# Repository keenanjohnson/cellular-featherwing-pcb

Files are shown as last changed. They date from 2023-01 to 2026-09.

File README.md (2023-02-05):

# cellular-featherwing-pcb
The PCB Design for a Cellular Adafruit Featherwing based on the Quectel BG96 LTE Cat M1 &amp; Cat NB1.

Based on the excellent [qTop Adafruit Feather design](https://www.iot-bots.com/collections/qtop-cellular/products/qtop-adafruit-feather-compatible-lte-cat-m1-nb-iot-gnss-shield) by [IOT-BOTS](https://www.iot-bots.com/)

# Current Status
This PCB is currently being produced by [JLPCB](https://jlcpcb.com/). The design has NOT been verified as functional yet until first production samples are tested.



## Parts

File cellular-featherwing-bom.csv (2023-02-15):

Comment | Designator | Footprint | JLCPCB Part #（optional）
22uF | C1,C2,C6,C7,C8 | 22 uF 0603 Capacitor | C59461
2.2uF | C3 | 2.2 uF 0402 Capacitor | C12530
0.1uF | C4,C11,C29,C34 | 0.1 uF 0402 Capacitor | C1525
33pF | C16,C17,C18,C22,C23 | 33 pF 0402 Capacitor | C1562
100nF | C20,C21 | 100 nF 0402 Capacitor | C1525
10pF | C24,C25 | 10 pF 0402 Capacitor | C32949
C_Polarized_US | C26,C28 | 330 碌F Molded Tantalum Capacitors 6 V 1411 (3528 Metric) 800mOhm | C347529
4.7uF | C30,C31,C33 | 4.7 碌F 卤20% 10V Ceramic Capacitor X5R 0402 (1005 Metric) | C23733
SMF05C | D1 | 12.5V Clamp 8A (8/20碌s) Ipp Tvs Diode Surface Mount SC-70-6 | C85191
0 Ohm Resistor | FB1,FB2,FB3,FB4 | 0805 (2012 Metric) 0 Ohm Resistor | C269721
SIM8060-6-0-14-00-A | J1 | SIM NANO HINGED, 6P, 1.40MM PROF | C111371
TSM-116-01-L-SV | J2 | Connector Header Surface Mount 16 position 0.100" (2.54mm)
TSM-112-01-L-SV | J3 | Connector Header Surface Mount 12 position 0.100" (2.54mm)
U.FL-R-SMT | J4 | U.FL (UMCC) Connector Receptacle, Male Pin 50Ohm Surface Mount Solder | C88373
1 uH | L1 | 1 碌H Shielded Molded Inductor 12 A 9mOhm Max 1616 (4040 Metric)
1.24M | R1 | 1.24M Ohm 0402 Resistor | C166533
182k | R2 | 182k Ohm 0402 Resistor | C226822
0 | R3,R6,R21,R22 | 0 Ohm 0402 Resistor | C17168
15k | R8 | 15k Ohm 0402 Resistor | C25756
470 | R14 | 470 Ohm 0402 Resistor | C25117
100k | R15 | 100k Ohm 0402 Resistor | C25741
BG96 | U1 | Quectel BG96 Cellular Module | C3010493
TPS63020DSJR | U2 | High Efficiency Single Inductor Buck-Boost Converter with 4A Switch 14-VSON -40 to 85 | C15483
TXB0108RGYR | U3 | TXB0108 8-Bit Bidirectional Voltage-Level Translator | C194701
MAX8868EUK30+T | U4 | Linear Voltage Regulator IC Positive Fixed 1 Output 150mA SOT-23-5 | C37970
D_TVS | VD1 | Varistor 1 Circuit Surface Mount, MLCV 0402 (1005 Metric) | C316053
BLUE | VD4 | Blue 470nm LED Indication - Discrete 3.2V 0603 (1608 Metric) | C72041
SS2030FL_R1_00001 | VD5,VD6 | Diode 30 V 2A Surface Mount SOD-123FL | C167645
DDTD123YC-7-F | VT3,VT4 | NPN PRE-BIASED 500mA SURFACE MOUNT TRANSISTOR | C280842

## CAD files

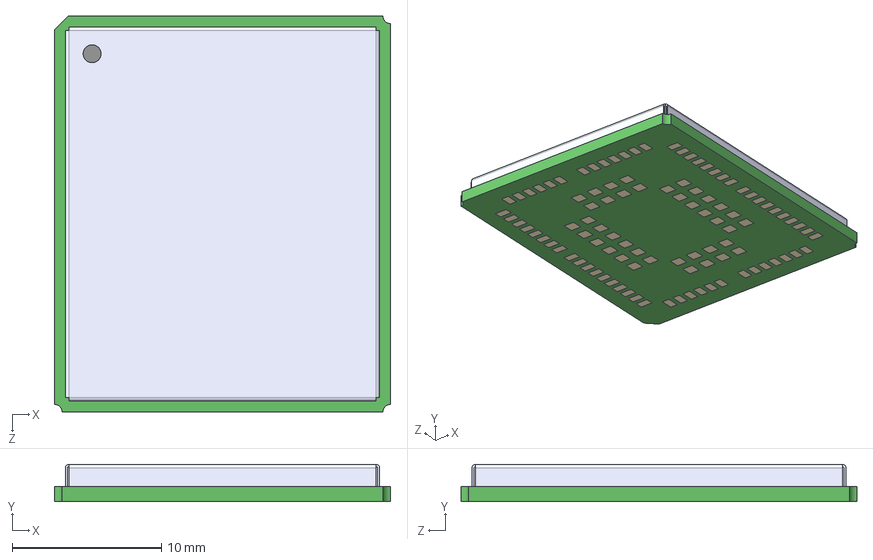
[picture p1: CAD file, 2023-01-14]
snapeda/BG96/BG96.step
22.5 x 2.50 x 26.5 mm

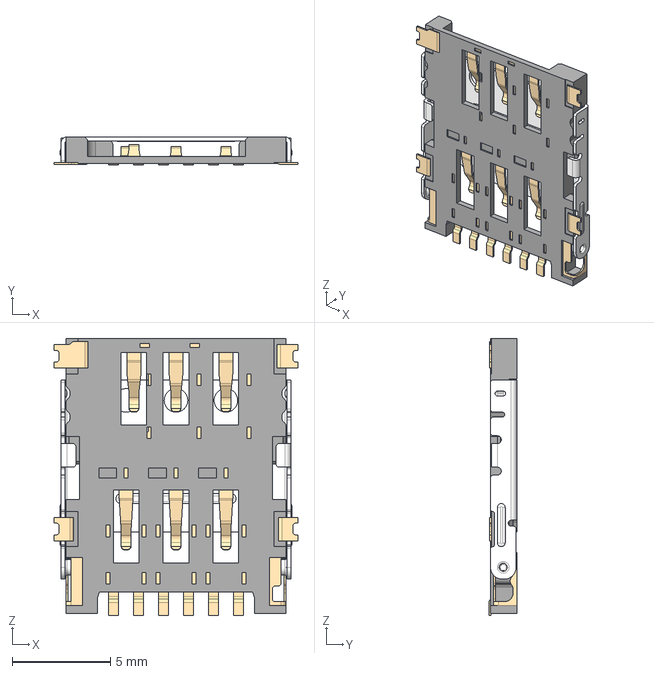
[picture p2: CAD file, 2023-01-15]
snapeda/SIM8060-6-0-14-00-A/SIM8060-6-0-14-00-A.stp
12.4 x 1.43 x 14.1 mm
SIM8060-6-0-14-00-A_PART2
SIM8060-6-0-14-00-A_PART1

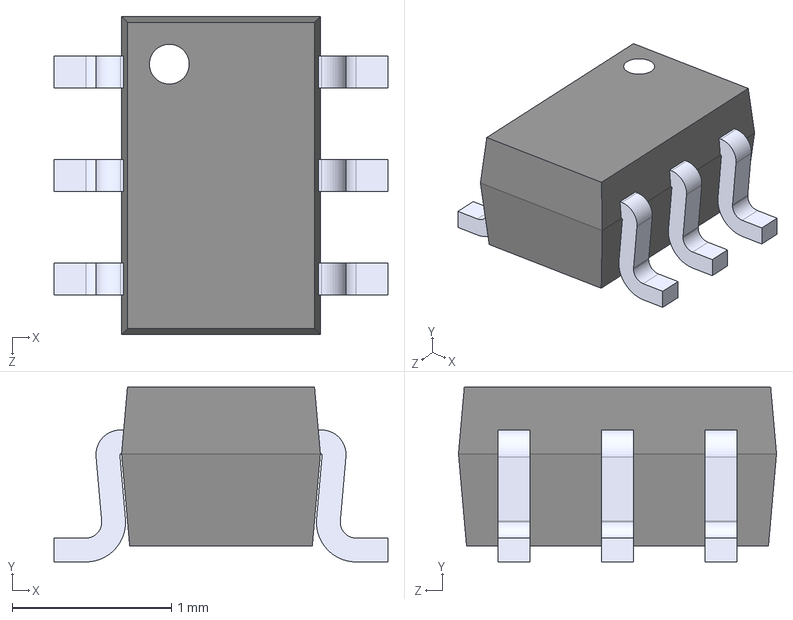
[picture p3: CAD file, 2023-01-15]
snapeda/SMF05C/SMF05C.step
2.10 x 1.10 x 2.00 mm

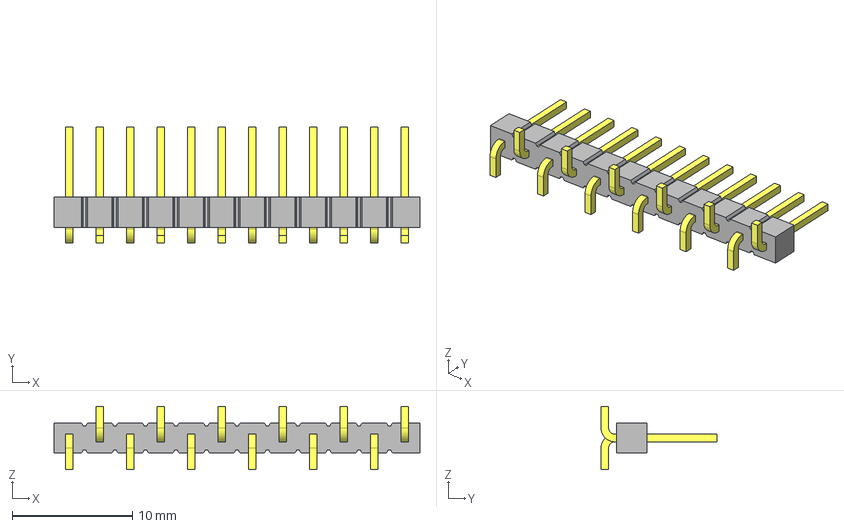
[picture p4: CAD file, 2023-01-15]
snapeda/TSM-112-01-L-SV/TSM-112-01-L-SV.step
30.5 x 9.65 x 5.28 mm
T-1S6-16(-01-12-SV)
TSM-112-01-SV_body

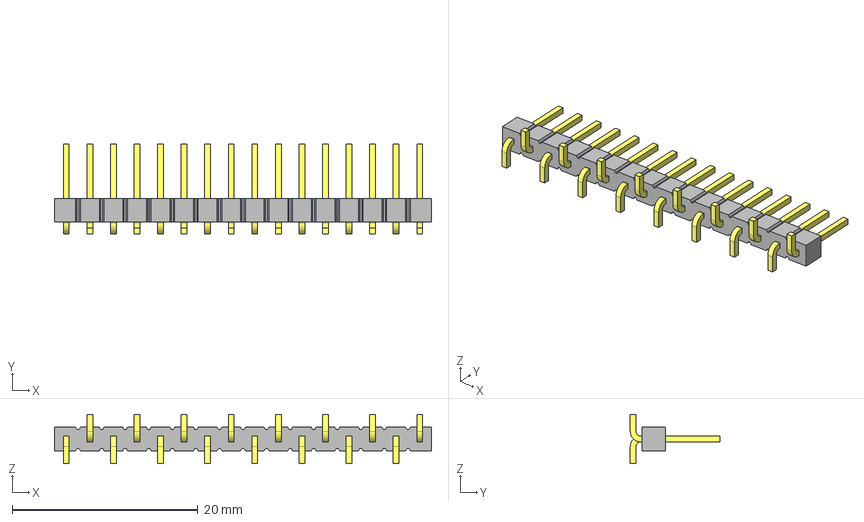
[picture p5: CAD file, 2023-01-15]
snapeda/TSM-116-01-L-SV/TSM-116-01-L-SV.step
40.6 x 9.65 x 5.28 mm
T-1S6-16(-01-16-SV)
TSM-116-01-SV_body

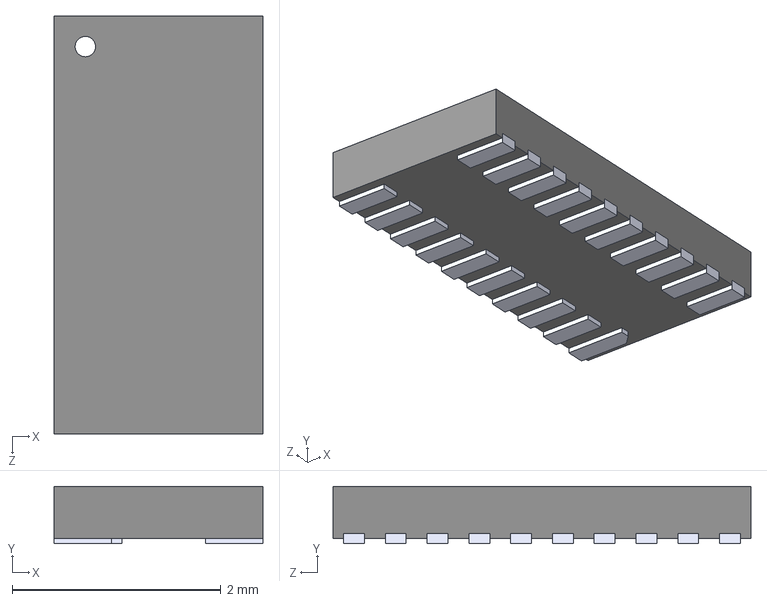
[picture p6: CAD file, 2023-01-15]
snapeda/TXB0108DQSR/TXB0108DQSR.step
2.00 x 0.55 x 4.00 mm

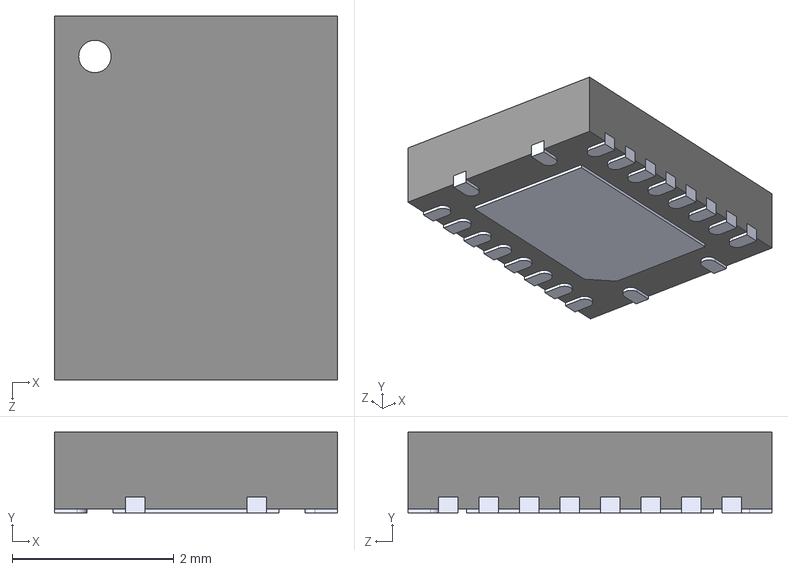
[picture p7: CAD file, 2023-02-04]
snapeda/TXB0108RGYR/TXB0108RGYR.step
3.50 x 1.00 x 4.50 mm

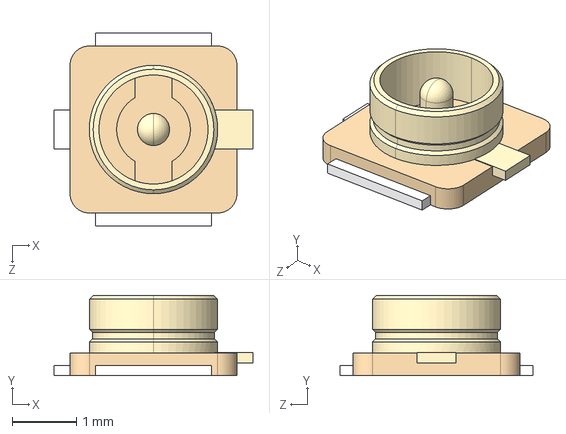
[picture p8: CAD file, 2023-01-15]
snapeda/U.FL-R-SMT_10_/U.FL-R-SMT_10_.step
3.10 x 1.25 x 3.00 mm

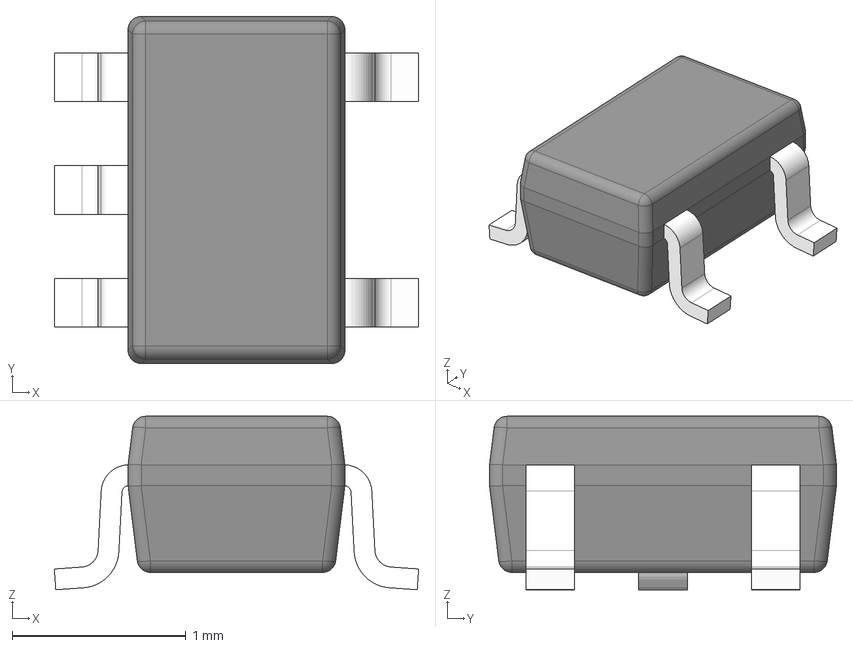
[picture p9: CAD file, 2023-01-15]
ultralibrarian/SN74AHC1G09DCKR/DCK0005A.stp
2.10 x 2.00 x 1.00 mm
BODY-SOT
LEAD-SOT x 5
PIN1-ID

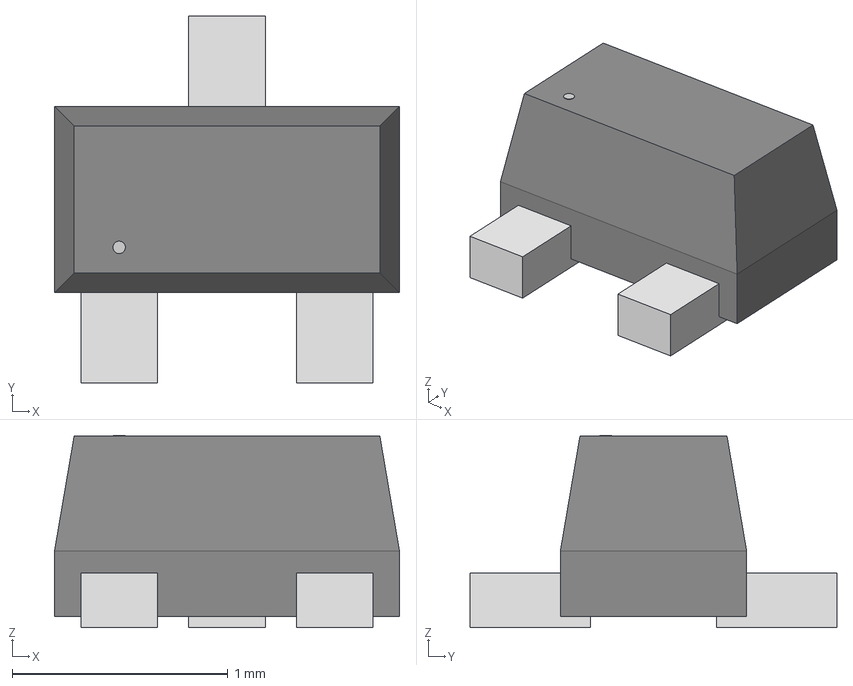
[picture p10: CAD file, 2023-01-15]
ultralibrarian/ul_DTC043TEBTL/TRANS_2SC4617EB_ROM.step
1.60 x 1.70 x 0.892 mm

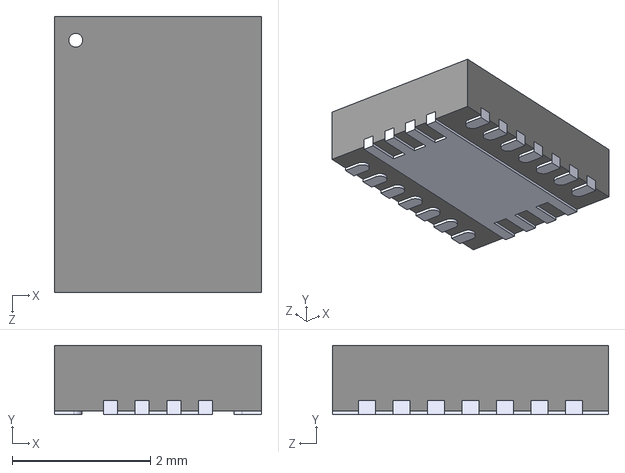
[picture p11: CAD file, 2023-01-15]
snapeda/TPS63020DSJR/TPS63020DSJR.step
3.00 x 1.00 x 4.00 mm

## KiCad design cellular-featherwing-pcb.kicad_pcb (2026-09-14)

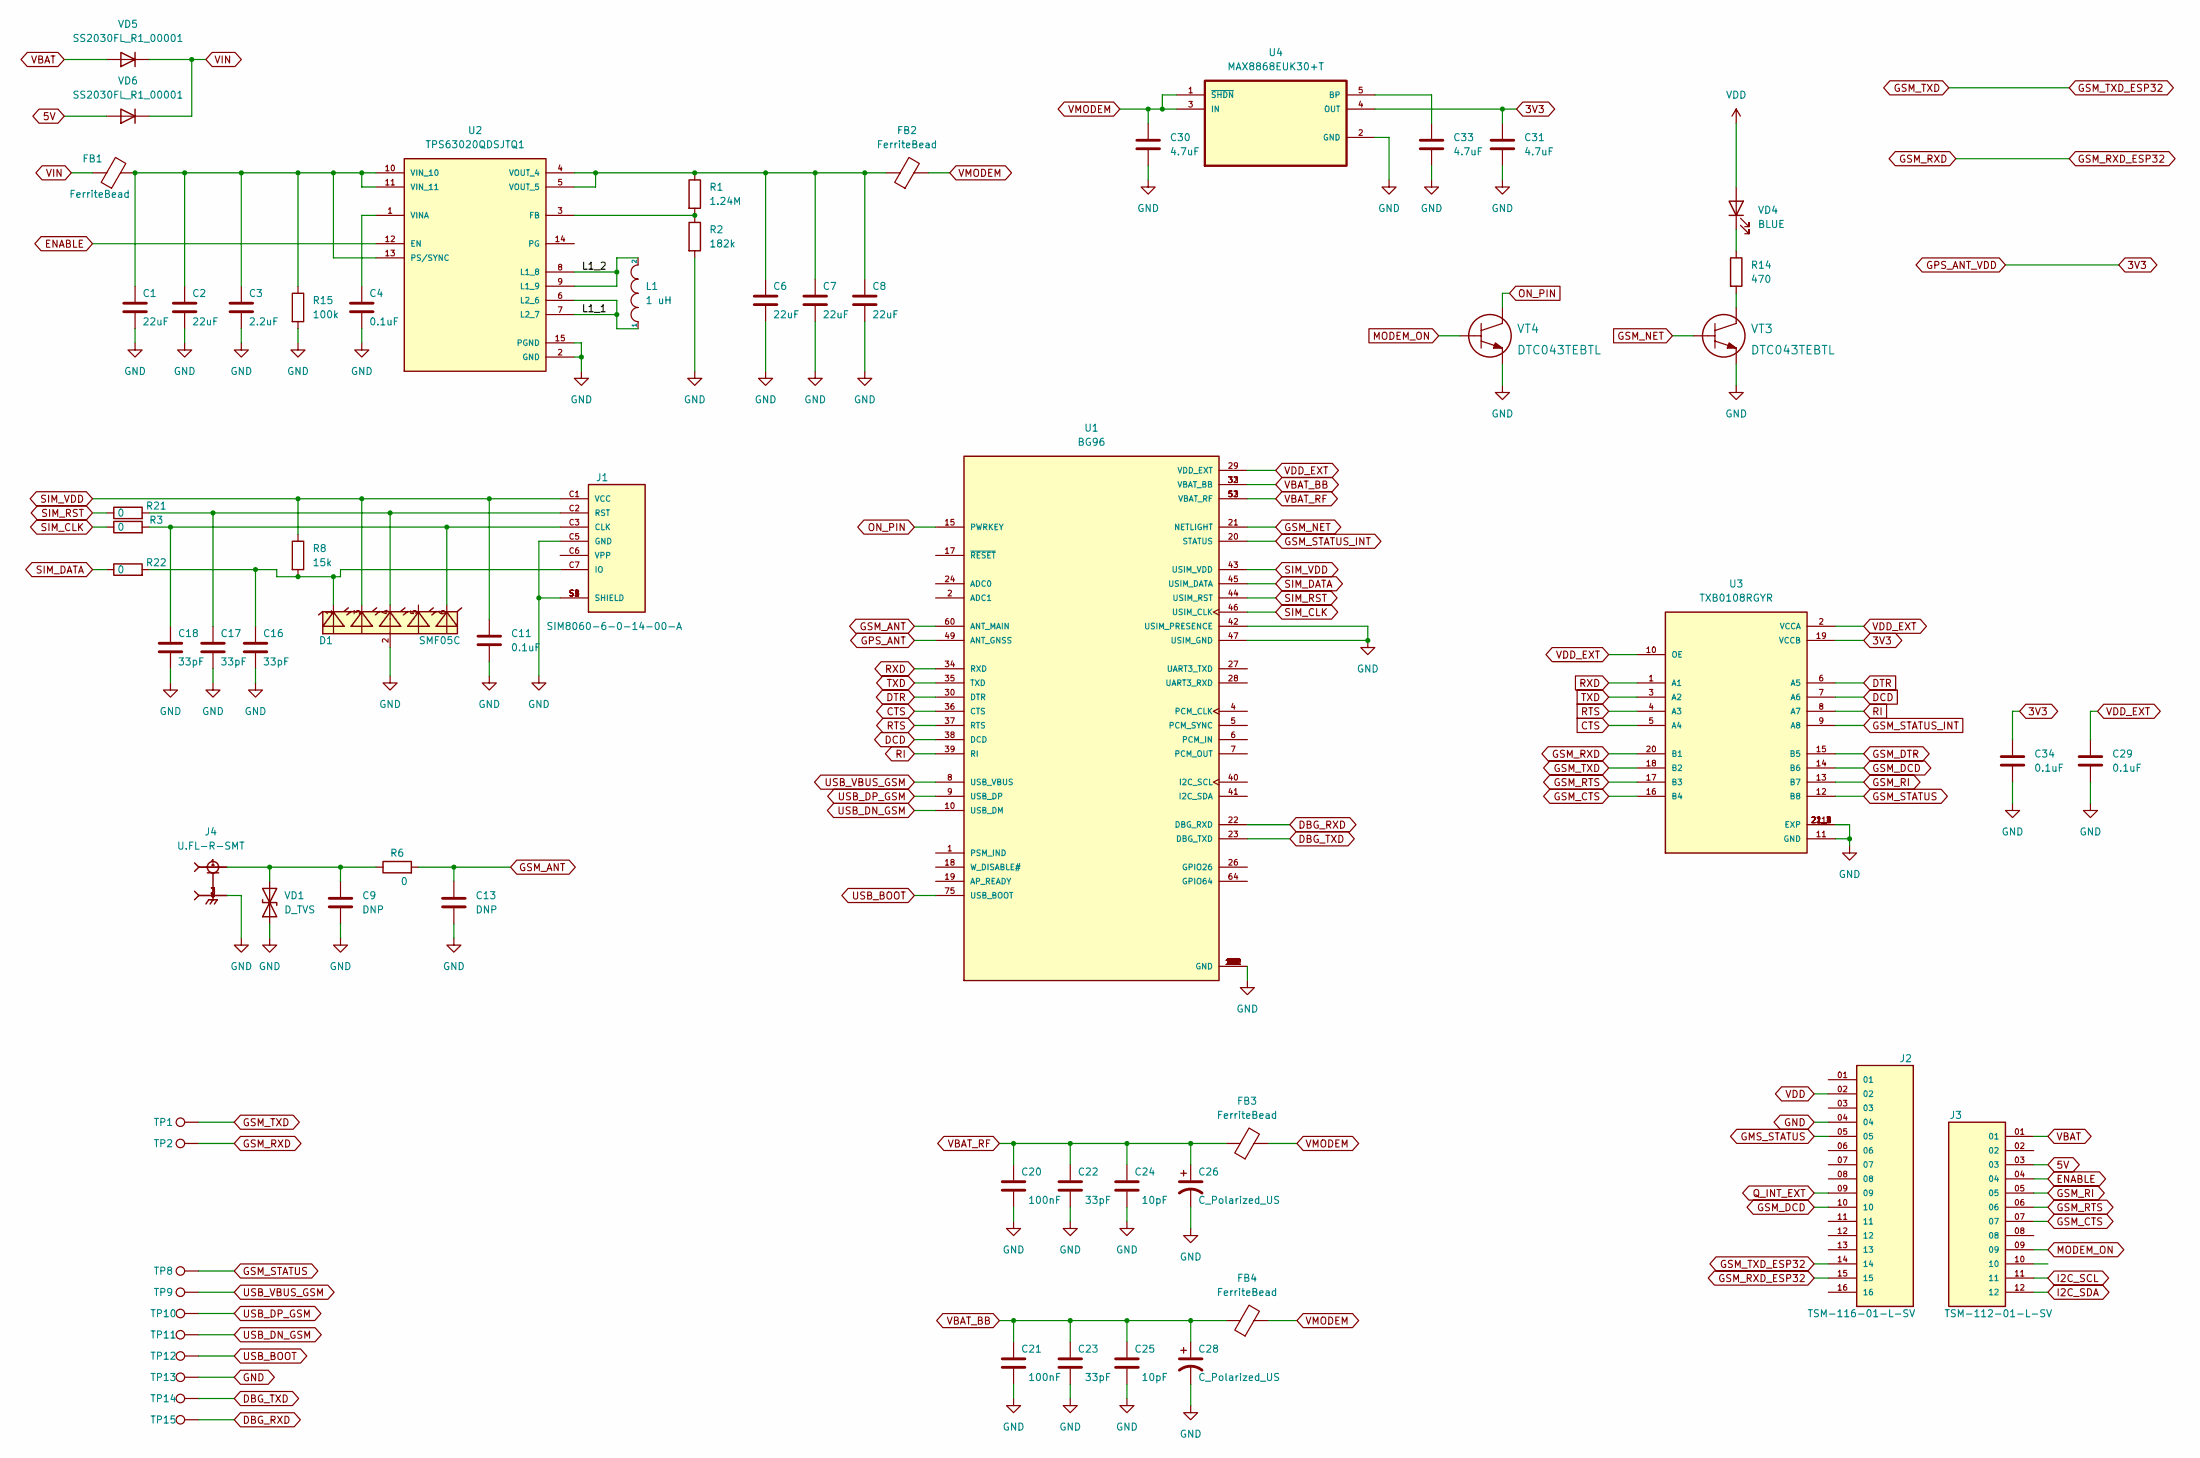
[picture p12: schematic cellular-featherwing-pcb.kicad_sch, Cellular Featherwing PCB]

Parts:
C1, C2, C6, C7, C8: 22uF; C_0603_1608Metric; MPN GCM1885C2A220JA16D; LCSC C415703
C3: 2.2uF; C_0402_1005Metric; MPN CL05A225MQ5NSNC; LCSC C12530
C4, C11, C29, C34: 0.1uF; C_0402_1005Metric; MPN CL05B104KO5NNNC; LCSC C1525
C9, C13: DNP; C_0402_1005Metric; MPN DNP; LCSC DNP
C16, C17, C18, C22, C23: 33pF; C_0402_1005Metric; MPN 0402CG330J500NT; LCSC C1562
C20, C21: 100nF; C_0402_1005Metric; MPN CL05B104KO5NNNC; LCSC C1525
C24, C25: 10pF; C_0402_1005Metric; MPN CL05C100JB5NNNC; LCSC C32949
C26, C28: C_Polarized_US; CP_EIA-3528-12_Kemet-T; MPN T490B337M006ATE800; LCSC C347529
C30, C31, C33: 4.7uF; C_0402_1005Metric; MPN CL05A475MP5NRNC; LCSC C23733
D1: SMF05C; SC70-6; MPN SMF05C.TCT; LCSC C85191
FB1, FB2, FB3, FB4: FerriteBead; R_0805_2012Metric; MPN 742792030; LCSC C15957
J1: SIM8060-6-0-14-00-A; GCT_SIM8060-6-0-14-00-A; MPN SIM8060-6-0-14-00-A; LCSC C111371
J2: TSM-116-01-L-SV; SAMTEC_TSM-116-01-L-SV; MPN TSM-116-01-L-SV
J3: TSM-112-01-L-SV; SAMTEC_TSM-112-01-L-SV; MPN TSM-112-01-L-SV
J4: U.FL-R-SMT; HRS_U.FL-R-SMT(10); MPN U.FL-R-SMT(10); LCSC C434808
L1: 1 uH; L_Coilcraft_XxL4020; MPN XGL4020-102MEC
R1: 1.24M; R_0402_1005Metric; MPN RC0402FR-071M24L; LCSC C166533
R2: 182k; R_0402_1005Metric; MPN AC0402FR-07182KL; LCSC C226822
R3, R6, R21, R22: 0; R_0402_1005Metric; MPN 0402WGF0000TCE; LCSC C17168
R8: 15k; R_0402_1005Metric; MPN 0402WGF1502TCE; JLCPCB 0402WGF1502TCE
R14: 470; C_0402_1005Metric; MPN 0402WGF4700TCE; JLCPCB 0402WGF4700TCE
R15: 100k; R_0402_1005Metric; MPN 0402WGF1003TCE; JLCPCB 0402WGF1003TCE
TP1, TP2, TP8, TP9, TP10, TP11, TP12, TP13, TP14, TP15: TestPoint; TestPoint_Pad_D1.0mm; MPN DNP; LCSC DNP
U1: BG96; Quectel_BG96; PARTREV 1.4; LCSC C3010493
U2: TPS63020QDSJTQ1; IC_TPS63020DSJR; MPN TPS63020QDSJTQ1; LCSC C202140
U3: TXB0108RGYR; IC_TXB0108RGYR; PARTREV H; JLCPCB Part #（optional ) C194701
U4: MAX8868EUK30+T; SOT95P280X145-5N; MPN MAX8868EUK30+T; LCSC C37970
VD1: D_TVS; D_0402_1005Metric; MPN EZA-EG2A50AX; LCSC C316053
VD4: BLUE; LED_0603_1608Metric; MPN 150060BS75000; LCSC C72041
VD5, VD6: SS2030FL_R1_00001; D_SOD-123F; MPN SS2030FL_R1_00001; LCSC C167645
VT3, VT4: DTC043TEBTL; SOT-23; MPN DTC043TEBTL; LCSC C2971747

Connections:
3V3: C31.1, C34.1, U3.19 (VCCB), U4.4 (OUT)
5V: J3.03, VD6.2 (A)
/L1_1: L1.1, U2.6 (L2_6), U2.7 (L2_7)
/L1_2: L1.2, U2.8 (L1_8), U2.9 (L1_9)
CTS: U1.36 (CTS), U3.5 (A4)
DBG_RXD: TP15.1, U1.22 (DBG_RXD)
DBG_TXD: TP14.1, U1.23 (DBG_TXD)
DCD: U1.38 (DCD), U3.7 (A6)
DTR: U1.30 (DTR), U3.6 (A5)
ENABLE: J3.04, U2.12 (EN)
GMS_STATUS: J2.05
GND: C1.2, C2.2, C3.2, C4.2, C6.2, C7.2, C8.2, C9.2, C11.2, C13.2, C16.2, C17.2, C18.2, C20.2, C21.2, C22.2, C23.2, C24.2, C25.2, C26.2, C28.2, C29.2, C30.2, C31.2, C33.2, C34.2, D1.2, J1.C5 (GND), J1.S1 (SHIELD), J1.S2 (SHIELD), J1.S3 (SHIELD), J1.S4 (SHIELD), J2.04, J4.2, J4.3, R2.2, R15.2, TP13.1, U1.3 (GND), U1.31 (GND), U1.42 (USIM_PRESENCE), U1.47 (USIM_GND), U1.48 (GND), U1.50 (GND), U1.54 (GND), U1.55 (GND), U1.58 (GND), U1.59 (GND), U1.61 (GND), U1.62 (GND), U1.67 (GND), U1.68 (GND), U1.69 (GND), U1.70 (GND), U1.71 (GND), U1.72 (GND), U1.73 (GND), U1.74 (GND), U1.79 (GND), U1.80 (GND), U1.81 (GND), U1.82 (GND), U1.89 (GND), U1.90 (GND), U1.91 (GND), U1.100 (GND), U1.101 (GND), U1.102 (GND), U2.2 (GND), U2.15 (PGND), U3.11 (GND), U3.21 (EXP), U3.21_1 (EXP), U3.21_2 (EXP), U3.21_3 (EXP), U3.21_4 (EXP), U4.2 (GND), VD1.1 (A1), VT3.2, VT4.2
GPS_ANT: U1.49 (ANT_GNSS)
GSM_ANT: C13.1, R6.2, U1.60 (ANT_MAIN)
GSM_CTS: J3.07, U3.16 (B4)
GSM_DCD: J2.10, U3.14 (B6)
GSM_DTR: U3.15 (B5)
GSM_NET: U1.21 (NETLIGHT), VT3.1
GSM_RI: J3.05, U3.13 (B7)
GSM_RTS: J3.06, U3.17 (B3)
GSM_RXD: J2.15, TP2.1, U3.20 (B1)
GSM_STATUS: TP8.1, U3.12 (B8)
GSM_STATUS_INT: U1.20 (STATUS), U3.9 (A8)
GSM_TXD: J2.14, TP1.1, U3.18 (B2)
I2C_SCL: J3.11
I2C_SDA: J3.12
MODEM_ON: J3.09, VT4.1
unnamed: C1.1, C2.1, C3.1, FB1.2, R15.1, U2.10 (VIN_10), U2.11 (VIN_11), U2.13 (PS/SYNC)
unnamed: C4.1, U2.1 (VINA)
unnamed: C6.1, C7.1, C8.1, FB2.1, R1.1, U2.4 (VOUT_4), U2.5 (VOUT_5)
unnamed: C9.1, J4.1, R6.1, VD1.2 (A2)
unnamed: C16.1, D1.1, J1.C7 (IO), R8.2, R22.2
unnamed: C17.1, D1.4, J1.C2 (RST), R21.2
unnamed: C18.1, D1.6, J1.C3 (CLK), R3.2
unnamed: C33.1, U4.5 (BP)
unnamed: R1.2, R2.1, U2.3 (FB)
unnamed: R14.1, VD4.1 (K)
unnamed: R14.2, VT3.3
ON_PIN: U1.15 (PWRKEY), VT4.3
Q_INT_EXT: J2.09
RI: U1.39 (RI), U3.8 (A7)
RTS: U1.37 (RTS), U3.4 (A3)
RXD: U1.34 (RXD), U3.1 (A1)
SIM_CLK: R3.1, U1.46 (USIM_CLK)
SIM_DATA: R22.1, U1.45 (USIM_DATA)
SIM_RST: R21.1, U1.44 (USIM_RST)
SIM_VDD: C11.1, D1.3, J1.C1 (VCC), R8.1, U1.43 (USIM_VDD)
TXD: U1.35 (TXD), U3.3 (A2)
USB_BOOT: TP12.1, U1.75 (USB_BOOT)
USB_DN_GSM: TP11.1, U1.10 (USB_DM)
USB_DP_GSM: TP10.1, U1.9 (USB_DP)
USB_VBUS_GSM: TP9.1, U1.8 (USB_VBUS)
VBAT: J3.01, VD5.2 (A)
VBAT_BB: C21.1, C23.1, C25.1, C28.1, FB4.1, U1.32 (VBAT_BB), U1.33 (VBAT_BB)
VBAT_RF: C20.1, C22.1, C24.1, C26.1, FB3.1, U1.52 (VBAT_RF), U1.53 (VBAT_RF)
VDD: J2.02, VD4.2 (A)
VDD_EXT: C29.1, U1.29 (VDD_EXT), U3.2 (VCCA), U3.10 (OE)
VIN: FB1.1, VD5.1 (K), VD6.1 (K)
VMODEM: C30.1, FB2.2, FB3.2, FB4.2, U4.1 (~SHDN), U4.3 (IN)

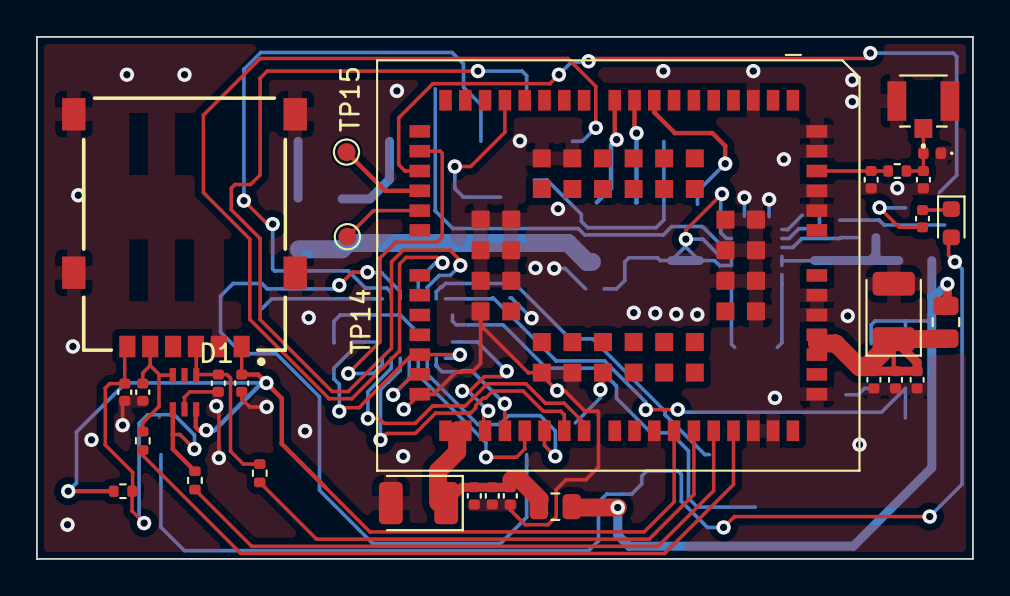
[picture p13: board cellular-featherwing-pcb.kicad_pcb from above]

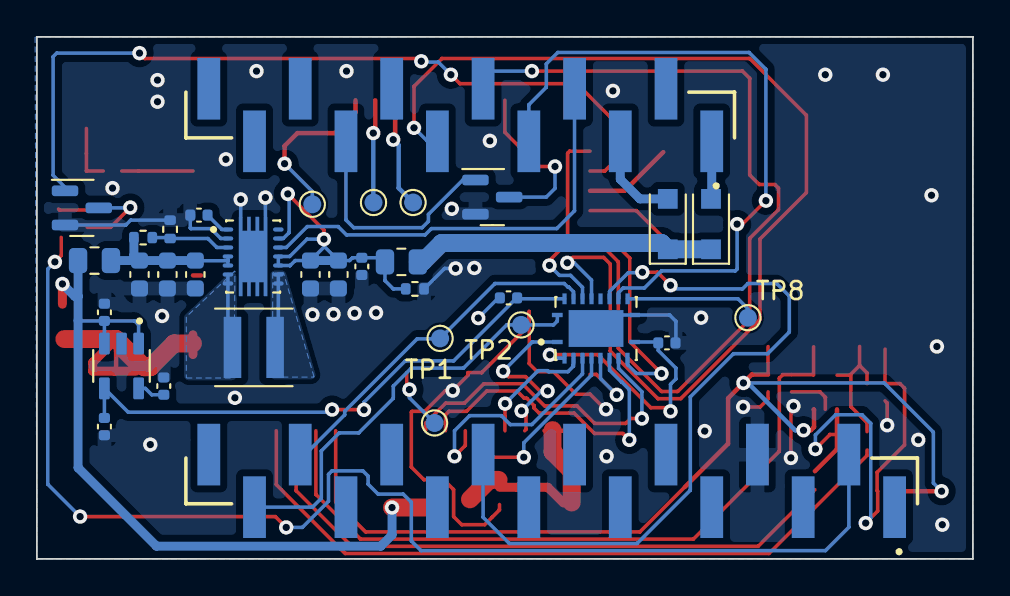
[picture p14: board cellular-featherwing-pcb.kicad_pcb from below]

Board: 2 copper layers, 52.0 x 29.0 mm, 64 parts (34 on the bottom side), 53 nets.

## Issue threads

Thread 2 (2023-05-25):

Resources for driving the module from MicroPython

josuah, 2023-05-25:
I hope this is the right place to collect information for a driver for this module.
Otherwise let me know I would move the content elsewhere...
Maybe also there is an ongoing effort somewhere for this?

In my understanding, LTE modules like this solely use a standard protocol based on AT commands (or at least, it is possible to operate them this way).
This protocol is exposed through various serial links, such as UART or USB.

With these two protocols, one does not require too much knowledge on the internals of the quectel module itself.

## Resources

- Getting started with poking around with AT commands:
https://www.emnify.com/developer-blog/at-commands-for-cellular-modules

- The original Quectel has a lot of information about how to integrate and use the module (bottom of the page):
https://www.quectel.com/product/lpwa-bg96-cat-m1-nb1-egprs

- • OS-IoT, the ATIS Open Source Internet of Things is an open source software library that simplifies the development of IoT devices, particularly small clients, that connect to the oneM2M e
cosystem.  -- [wikiepdia](https://en.wikipedia.org/wiki/OneM2M#Open_Source_Projects)
https://os-iot.org/c-library/
https://atis.codebasehq.com/atis-os-iot/atis-os-iot-bg96.git
https://www.os-iot.org/wp-content/uploads/2019/01/os-iot-bg96-guide.pdf

- It might be the `qmi_wwan` and `qcserial` drivers on Linux, so there are chances that these are the same for all Quectel devices:
https://github.com/torvalds/linux/blob/master/drivers/usb/serial/qcserial.c
https://github.com/torvalds/linux/blob/master/drivers/net/usb/qmi_wwan.c

- A repository with just the Quectel Linux USB drivers:
https://github.com/bacnh85/Quectel_Linux_USB_Driver

- An arduino library showing compact implementation of everything needed:
https://github.com/m2m-solutions/M2M_Quectel/blob/master/src/M2M_Quectel.cpp

- MicroPython might as well be able to run onto the Quectel module itself? I am still confused about this.
https://blog.adafruit.com/2021/10/12/quecpython-is-quectels-port-of-micropython-for-modules/
https://python.quectel.com/home

josuah, 2023-05-25:
- "QMI", which seems to be what Linux uses for Quectel modules:
  https://en.wikipedia.org/wiki/Qualcomm_MSM_Interface

- QMI seems native to Qualcomm, but picked-up by Quectel and many others as an ad-hoc standard:
  “Qualcomm default seems to permit +CLVL, +CKPD, +CMUT, +CTSA, +CBKLT, +CFUN, +CDIS, +CRSL, +CMAR, +CSO, +CSS, +CBC, $QCPWRDN and this may be **extended by vendor-specific commands, such as +QFOTADL in the Quectel case**”
  https://osmocom.org/projects/quectel-modems/wiki/QMI

- The libqmi is what powers Linux's `qmi-utils` that can be used to configure such a module from Linux:
   https://www.freedesktop.org/wiki/Software/libqmi/

- This project collects drivers and libraries for these WWAN protocols: QMI, MBIM, QRTR. These could be used as reference. It contains libqmi.
  https://github.com/linux-mobile-broadband

josuah, 2023-05-25:
Here is a script that I use to connect to Internet using qmicli on Linux.

This would allow to test the module to make sure the hardware works, before starting a custom implementation for it.

For instance, using an USB-UART external dongle (`/dev/ttyACM0` or `/dev/ttyUSB0`) attached to the module's UART instead the internal USB of the module ( `/dev/cdc-wdm0`).

```shell
#!/bin/sh

# change /dev/cdc-wdm0 to whatever serial interface you have that can accept AT commands...

# adjust these for your SIM provider: public information
apn=orange user=orange pass=orange

qmicli -d /dev/cdc-wdm0 \
  --dms-set-operating-mode="online"

ip link set wwan0 down

qmicli -d /dev/cdc-wdm0 \
  --set-expected-data-format="raw-ip"

ip link set wwan0 up

qmicli -d /dev/cdc-wdm0 \
  --device-open-proxy \
  --device-open-net="net-raw-ip|net-no-qos-header" \
  --wds-start-network="apn='$apn',username='$user',password='$pass',ip-type=4" \
  --client-no-release-cid

qmicli -d /dev/cdc-wdm0 \
  --dms-get-operating-mode

qmicli -d /dev/cdc-wdm0 \
  --nas-get-signal-strength

qmicli -d /dev/cdc-wdm0 \
  --nas-get-home-network

udhcpc -qf \
  -i wwan0
```
From https://www.switchdoc.com/2021/05/tutorial-using-cellular-modems-with-the-raspberry-pi-4b/

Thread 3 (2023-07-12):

More affordable SIMCom A7680C-LAAS

josuah, 2023-07-12:
As said on the [chat](https://discord.com/channels/870113194289532969/905650193268080640/1128817480186470431) verbatim:

Through conversations in MicroPython, this part came-up:
https://www.lcsc.com/product-detail/2G-3G-4G-5G-Modules_SIMCom-Wireless-Solutions-A7680C-LAAS_C2981435.html

It is a lot less expensive than the alternatives like Quectel EC25
Some module for it would be $20 shipping and antenna included:
https://www.aliexpress.com/item/1005005131888666.html

josuah, 2023-07-12:
Linking the MicroPython server conversation as well:
https://github.com/keenanjohnson/cellular-featherwing-pcb/issues/3

josuah, 2023-07-14:
Important point: The A7680C-LAAS module in particular is only working with Chinese network standards.
There might be an equivalent module for different zones.
Worth checking before picking the actual part.

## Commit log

2023-01-14 Project start: Blank files
    [cellular-featherwing-pcb.kicad_pcb, cellular-featherwing-pcb.kicad_sch]
2023-01-14 snapeda: Adding bg96
    [BG96.step]
2023-01-14 Add Bg96 to schematic
    [cellular-featherwing-pcb.kicad_pcb, cellular-featherwing-pcb.kicad_sch]
2023-01-14 CI: Disable BOM
2023-01-14 .gitignore: Ignore kicad backups
2023-01-15 Footprints for all major components
    [DCK0005A.stp, SMF05C.step, TPS63020DSJR.step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]
2023-01-15 Add board outline
    [cellular-featherwing-pcb.kicad_pcb]
2023-01-15 Fix 3D model for bg96
    [cellular-featherwing-pcb.kicad_pcb]
2023-01-15 Add pn for gate
    [cellular-featherwing-pcb.kicad_sch]
2023-01-15 Routing progress
    [cellular-featherwing-pcb.kicad_pcb, cellular-featherwing-pcb.kicad_sch]
2023-01-15 Add ufl connector
    [SIM8060-6-0-14-00-A.stp, U.FL-R-SMT_10_.step, cellular-featherwing-pcb.kicad_pcb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]
2023-01-15 Wired up bg96 in schematic
    [cellular-featherwing-pcb.kicad_sch]
2023-01-15 schematic updates
    [cellular-featherwing-pcb.kicad_pcb, cellular-featherwing-pcb.kicad_sch]
2023-01-15 More progress
    [TRANS_2SC4617EB_ROM.step, cellular-featherwing-pcb.kicad_pcb, cellular-featherwing-pcb.kicad_sch]
2023-01-15 Schematic updates for sim card
    [cellular-featherwing-pcb.kicad_sch]
2023-01-15 finished schematic for sim card
    [cellular-featherwing-pcb.kicad_sch]
2023-01-15 Wired network LED in schematic
    [cellular-featherwing-pcb.kicad_pcb, cellular-featherwing-pcb.kicad_sch]
2023-01-15 Wired all the jumpers
    [cellular-featherwing-pcb.kicad_pcb, cellular-featherwing-pcb.kicad_sch]
2023-01-15 Work on jumpers
    [cellular-featherwing-pcb.kicad_sch]
2023-01-16 schematic complete
    [cellular-featherwing-pcb.kicad_pcb, cellular-featherwing-pcb.kicad_sch]
2023-01-16 All footprints assigned
    [cellular-featherwing-pcb.kicad_pcb, cellular-featherwing-pcb.kicad_sch]
2023-01-16 Fixed drc and imported to pcb
    [cellular-featherwing-pcb.kicad_pcb, cellular-featherwing-pcb.kicad_sch]
2023-01-17 starting component layout
    [cellular-featherwing-pcb.kicad_pcb, cellular-featherwing-pcb.kicad_sch]
2023-01-17 Placement work
    [cellular-featherwing-pcb.kicad_pcb]
2023-01-17 Finished board outline and feather placements
    [cellular-featherwing-pcb.kicad_pcb]
2023-01-17 Placed quectel
    [cellular-featherwing-pcb.kicad_pcb]
2023-01-18 Parts placement
    [cellular-featherwing-pcb.kicad_pcb, cellular-featherwing-pcb.kicad_sch]
2023-01-18 Placed all components
    [cellular-featherwing-pcb.kicad_pcb, cellular-featherwing-pcb.kicad_sch]
2023-01-25 All components placed
    [cellular-featherwing-pcb.kicad_pcb, cellular-featherwing-pcb.kicad_sch]
2023-01-25 permanently linked 3d model
    [cellular-featherwing-pcb.kicad_pcb]
2023-01-25 Small updates
    [cellular-featherwing-pcb.kicad_pcb]
2023-02-02 Updates from Javier
    [cellular-featherwing-pcb.kicad_pcb]
2023-02-02 Updated board from javier
    [cellular-featherwing-pcb.kicad_pcb]
2023-02-03 All items routed
    [cellular-featherwing-pcb.kicad_pcb, cellular-featherwing-pcb.kicad_sch]
2023-02-03 Clean DRC
    [cellular-featherwing-pcb.kicad_pcb]
2023-02-03 Routing complete
    [cellular-featherwing-pcb.kicad_pcb, cellular-featherwing-pcb.kicad_sch]
2023-02-03 DRC and 3D Model Adjustments
    [cellular-featherwing-pcb.kicad_pcb, cellular-featherwing-pcb.kicad_sch]
2023-02-03 Add part numbers and BOM
    [cellular-featherwing-pcb.kicad_sch]
2023-02-03 add bom
    [cellular-featherwing-pcb.csv]
2023-02-03 Update BOM
    [cellular-featherwing-pcb.csv]
2023-02-03 POS Files
    [cellular-featherwing-pcb-all-pos.csv, cellular-featherwing-pcb-bottom-pos.csv, cellular-featherwing-pcb-top-pos.csv]
2023-02-03 Adding lcsc part numbers for jlpcb
    [cellular-featherwing-pcb.kicad_sch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]
2023-02-03 Files sent to jlpcb
    [cellular-featherwing-bom.csv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]
2023-02-04 Update u.fl lcsc part number
    [cellular-featherwing-bom.csv]
2023-02-04 Updates for jlpcb
    [TXB0108RGYR.step, cellular-featherwing-bom.csv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]
2023-02-04 Adding gerbers
    [cellular-featherwing-pcb-B_Cu.gbr, cellular-featherwing-pcb-B_Mask.gbr, cellular-featherwing-pcb-B_Paste.gbr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]
2023-02-05 Updated small footprint for pcb production
    [cellular-featherwing-bom.csv]
2023-02-14 #1 Connected LED
    [cellular-featherwing-pcb.kicad_pcb, cellular-featherwing-pcb.kicad_sch]
2023-02-14 New fab files
    [cellular-featherwing-bom.csv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]
2023-02-14 Update npn transitor
    [cellular-featherwing-bom.csv, cellular-featherwing-pcb.kicad_pcb, cellular-featherwing-pcb.kicad_sch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]
2023-02-14 Updated gerbers
    [cellular-featherwing-pcb-B_Cu.gbr, cellular-featherwing-pcb-B_Mask.gbr, cellular-featherwing-pcb-B_Paste.gbr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]
2023-02-14 Updated bom back to tps63020dsjr and 3.8 volts
    [cellular-featherwing-bom.csv]
2023-02-15 Fixed duplicate r1 in BOM
    [cellular-featherwing-bom.csv]
2026-09-14 Update to kicad 10
    [cellular-featherwing-pcb.kicad_pcb, cellular-featherwing-pcb.kicad_sch]
2026-09-14 Update 3d models for all parts
    [cellular-featherwing-pcb.kicad_pcb]

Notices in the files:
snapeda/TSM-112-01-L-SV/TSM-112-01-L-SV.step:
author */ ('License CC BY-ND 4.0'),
